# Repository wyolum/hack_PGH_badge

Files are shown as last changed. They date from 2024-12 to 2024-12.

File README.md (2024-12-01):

# hack_PGH_badge
* Badge PCB kit for hackPGH, for "learn to solder" and "learn to lasercut" classes
* Can be used for basic soldering (through hole parts) or advanced soldering (surface mount parts)

***FEATURES***
1. Four LED's with series current limit resistors
2. Two CR2032 Coin Batteries
3. Use slow fade multi-color LEDs, or all White LEDs or whatever you choose
5. The simple version is just battery, resistors and LEDs.
6. The fancy version is with two US1881 magnetic hall latch sensors - see notes in the schematic (PDF)

***RENDERS***
rev1 renders
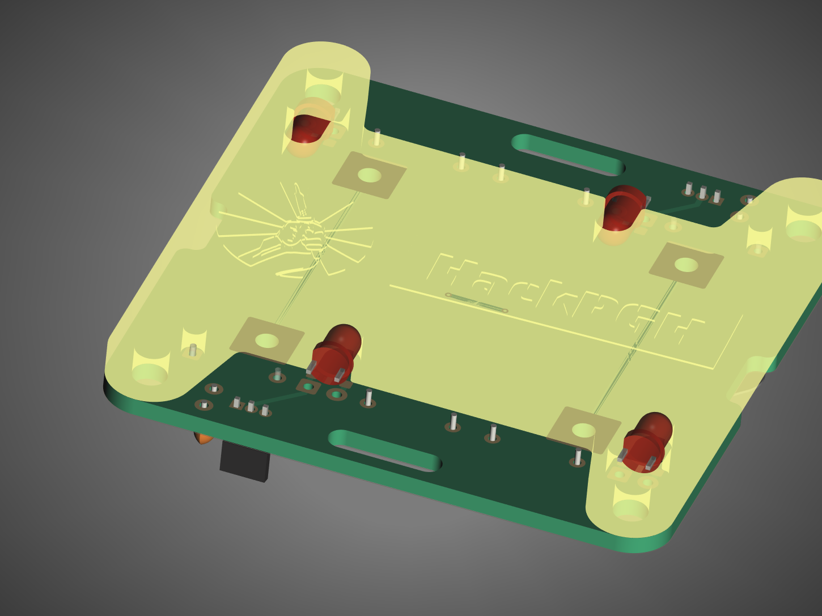
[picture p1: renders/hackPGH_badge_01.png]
hackPGH Badge


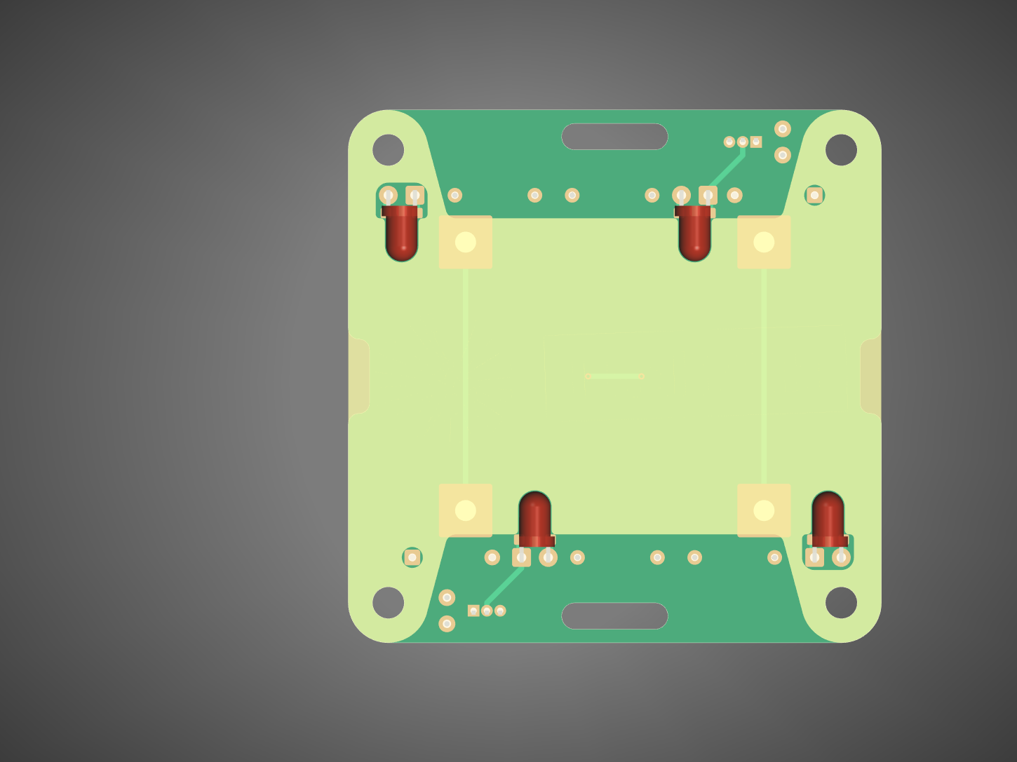
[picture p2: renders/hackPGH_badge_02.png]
hackPGH Badge


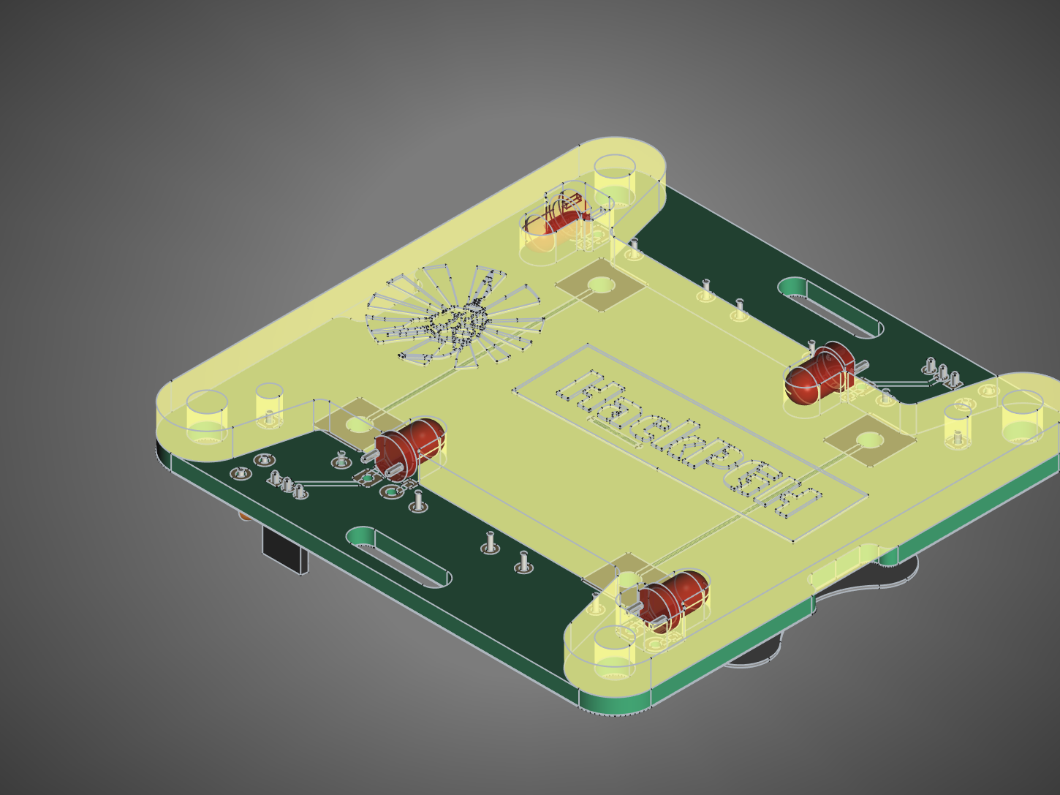
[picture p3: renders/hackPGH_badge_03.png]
hackPGH Badge


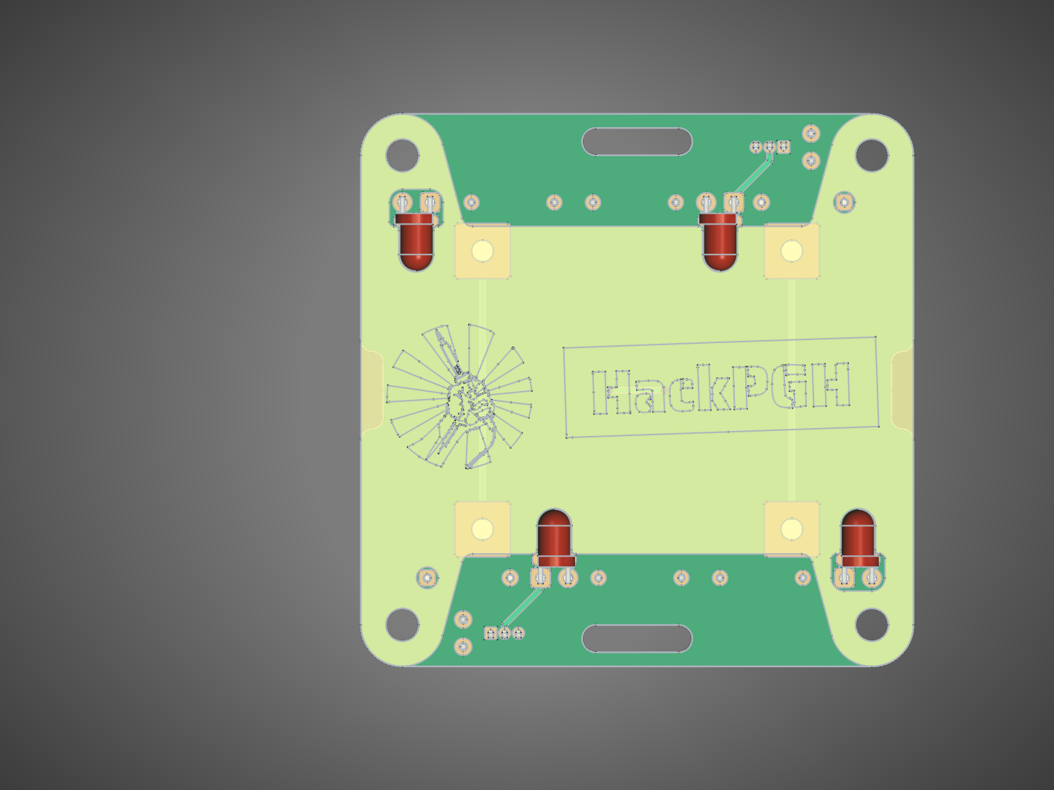
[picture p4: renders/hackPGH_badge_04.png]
hackPGH Badge


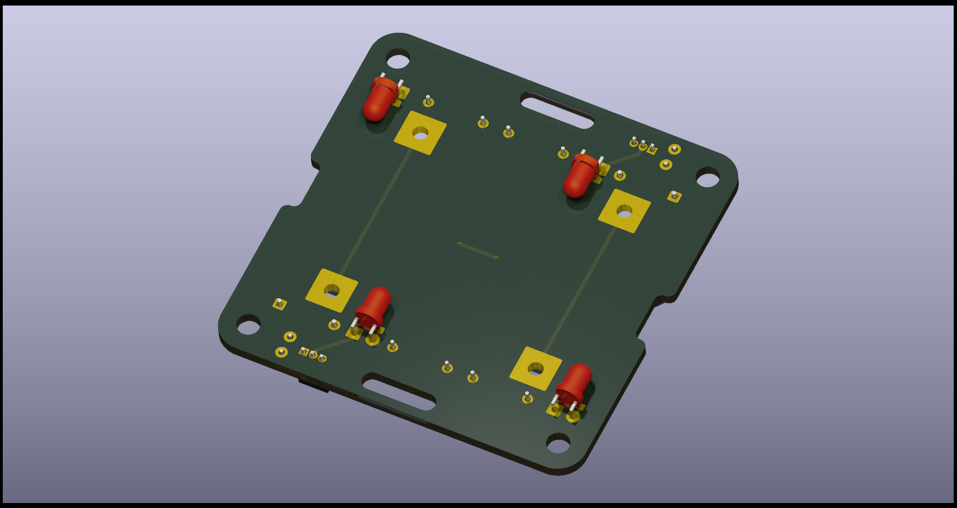
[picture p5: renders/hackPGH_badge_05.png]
hackPGH Badge


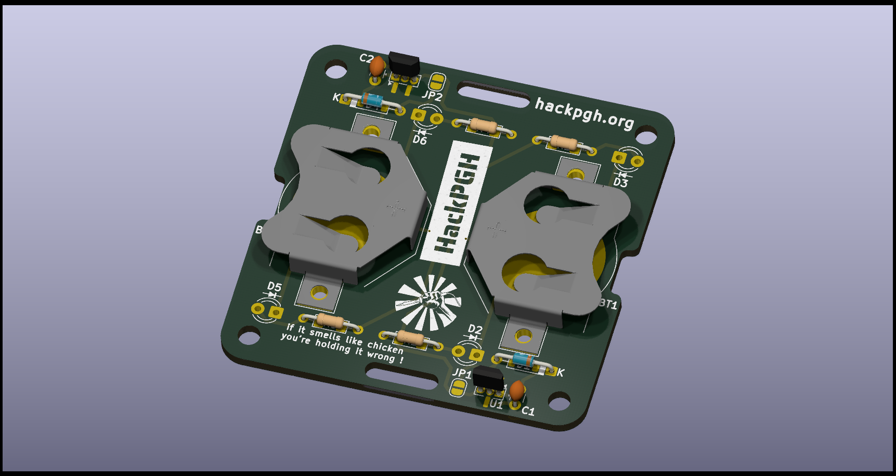
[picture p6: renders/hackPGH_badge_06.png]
hackPGH Badge


License
-------
[CERN Open Hardware Licence v1.2 ]

[CERN Open Hardware Licence v1.2 ]:http://www.ohwr.org/attachments/2388/cern_ohl_v_1_2.txt

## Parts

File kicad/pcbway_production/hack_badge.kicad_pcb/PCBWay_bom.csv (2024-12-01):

Designator | Quantity | Value | Footprint | Package | MPN | DNP | Mount_Type | Description | MF | MAXIMUM_PACKAGE_HEIGHT | Check_prices | STANDARD | PARTREV | SnapEDA_Link | MP | Description_1
BT1, BT2 | 2 | 3V | BatteryHolder_Keystone_3002_1x2032 |  |  |  | smt | CR2032
C1, C2 | 2 | 100nF | C_Disc_D3.0mm_W1.6mm_P2.50mm |  |  |  | tht | Unpolarized capacitor
D1, D4 | 2 | D_Schottky | D_SOD-123_DO-34_SOD68_P7.62mm_Horizontal |  |  |  | tht | Schottky diode, filled shape
D2, D3, D5, D6 | 4 | LED | LED_D3.0mm_Dialight_598 |  |  |  | tht | Light emitting diode, filled shape
R1, R2, R3, R4 | 4 | 2E2 | R_1206_Axial_DIN0204_L3.6mm_D1.6mm_P7.62mm_Horizontal |  |  |  | tht | Resistor
U1, U2 | 2 | US1881EUA-AAA-000-BU | TO92127P410H430-3_TSOT-23 | TO-92-3L-3 Melexis |  |  | tht |  | Melexis Technologies | 4.3mm | https://www.snapeda.com/parts/US1881EUA-AAA-000-BU/Melexis+Technologies+NV/view-part/?ref=eda | IPC-2221/IPC-2222 | 010 | https://www.snapeda.com/parts/US1881EUA-AAA-000-BU/Melexis+Technologies+NV/view-part/?ref=snap | US1881EUA-AAA-000-BU | Digital Switch Latch Open Drain Hall Effect TO-92-3

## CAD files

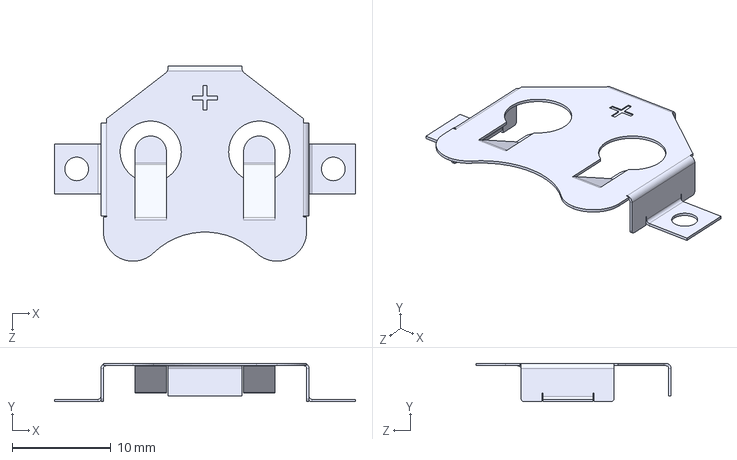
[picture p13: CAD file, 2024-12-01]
3D_2D_assets/BAT_HLD_003_SMT/BAT-HLD-003-SMT.step
30.5 x 3.90 x 19.8 mm

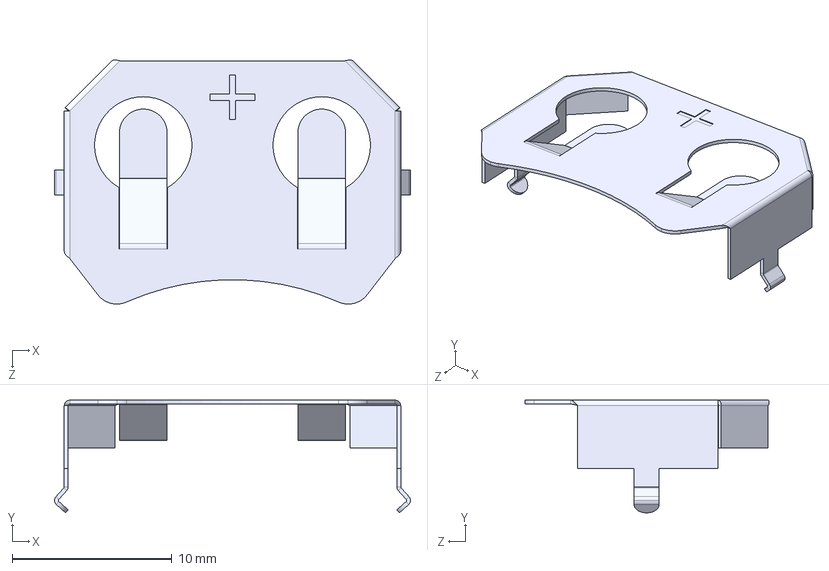
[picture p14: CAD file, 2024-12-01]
3D_2D_assets/BK_913/BK-913.step
22.3 x 7.06 x 15.3 mm

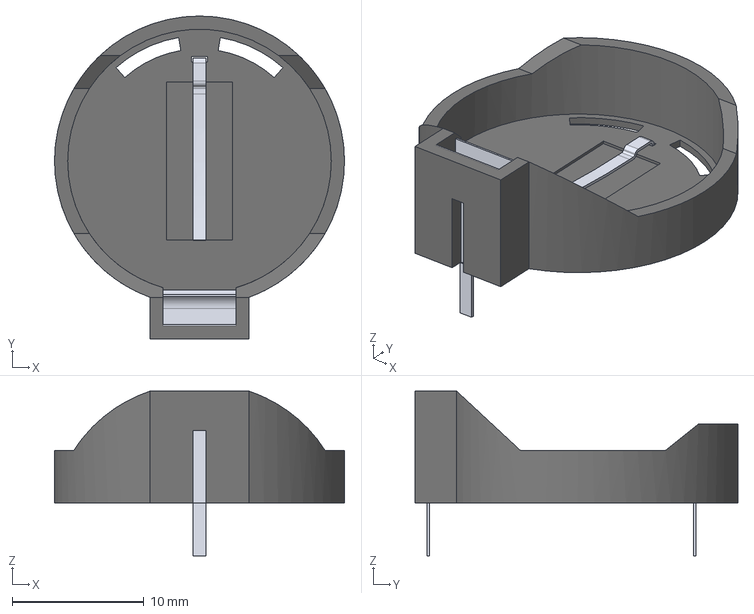
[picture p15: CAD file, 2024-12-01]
3D_2D_assets/CR2032_HOR_HOLD.step
22.0 x 24.5 x 12.5 mm

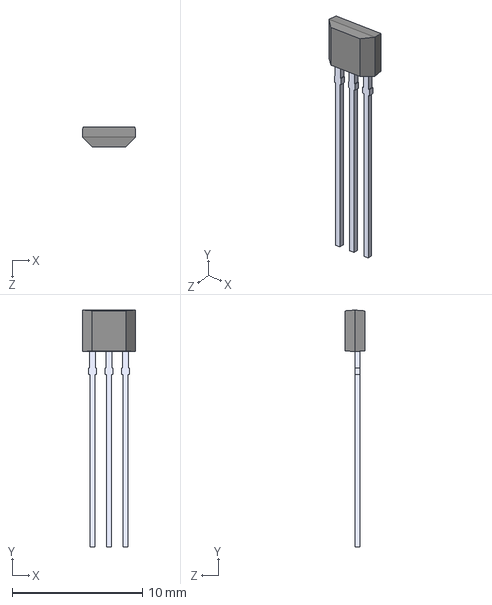
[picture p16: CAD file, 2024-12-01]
3D_2D_assets/US1881EUA-AAA-000-BU/US1881EUA-AAA-000-BU.step
4.10 x 18.2 x 1.50 mm

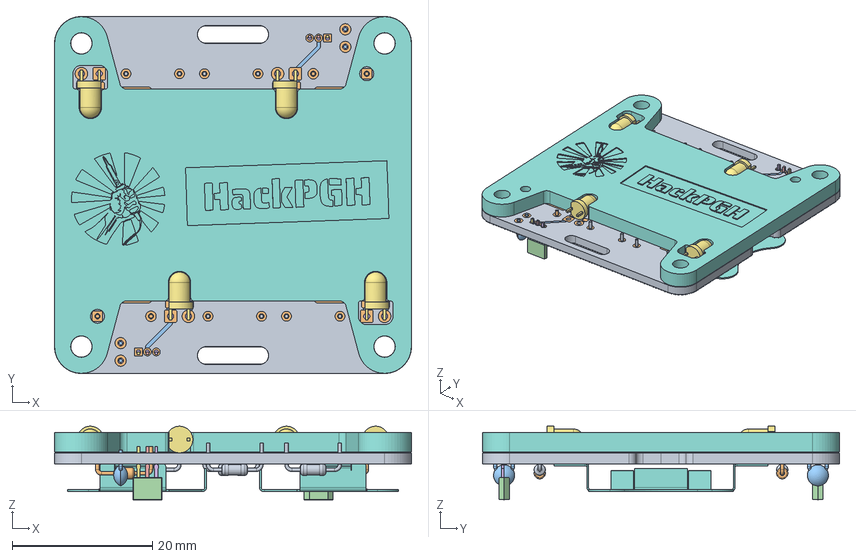
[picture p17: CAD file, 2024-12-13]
freecad/hackPGH_badge_v2.FCStd
50.9 x 50.9 x 10.5 mm
Pcb_8119
topPads_8119
topTracks_8119
botPads_8119
botTracks_8119
botSilks_2b00
D5_LED_D3.0mm_4dba36d6a966 x 4
BT1_BAT-HLD-003-SMT_d9d281af9b58 x 2
R1_R_Axial_DIN0204_L36mm_D16mm_P762mm_Horizontal_dcc7a843ff6f x 4
D4_D_DO-34_SOD68_P7.62mm_Horizontal_3fdec8da069c x 2
C2_C_Disc_D30mm_W20mm_P250mm_ea60b1ea7e60 x 2
TO92127P410H430-3 x 2
TO92127P410H430-004 x 2
TO92127P410H430-005 x 2
TO92127P410H430-006 x 2
Body_Acrylic

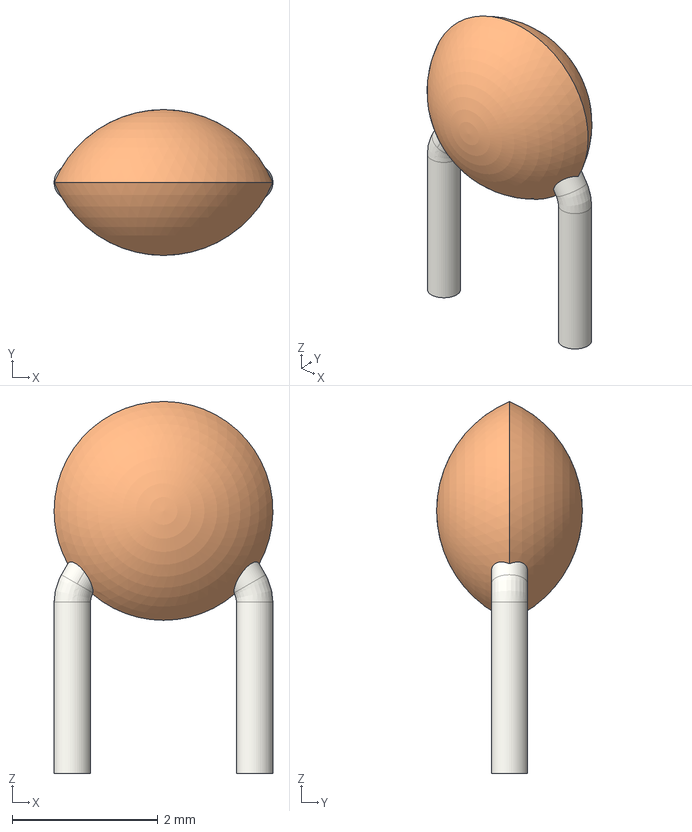
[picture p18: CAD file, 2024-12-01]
kicad/Library_3D_CAD_models/C_Disc_D3.0mm_W2.0mm_P2.50mm.step
3.00 x 2.00 x 5.10 mm

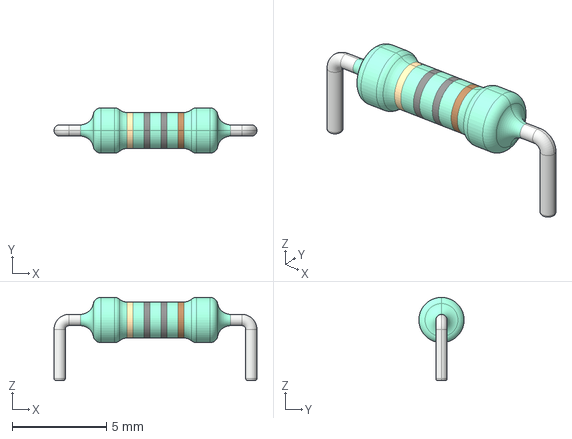
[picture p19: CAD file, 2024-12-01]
3D_2D_assets/Res40-Axial_Short_0.25W-10R.step
10.8 x 2.40 x 4.41 mm

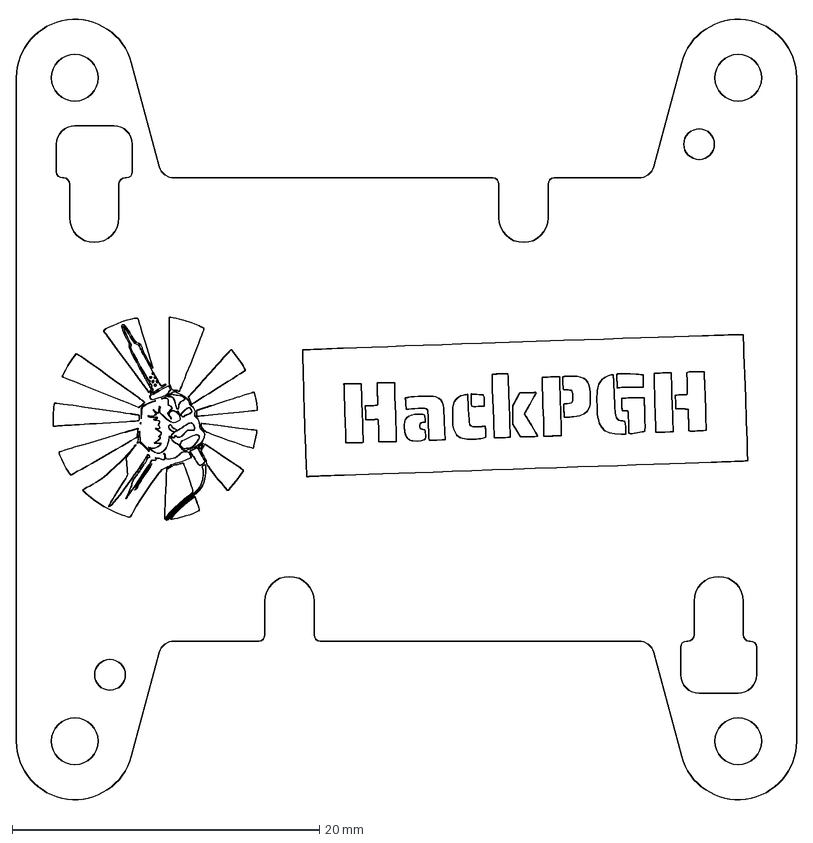
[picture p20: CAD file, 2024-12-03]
freecad/hackPGH_badge_v2_acrylic.dxf
50.8 x 51.2 mm

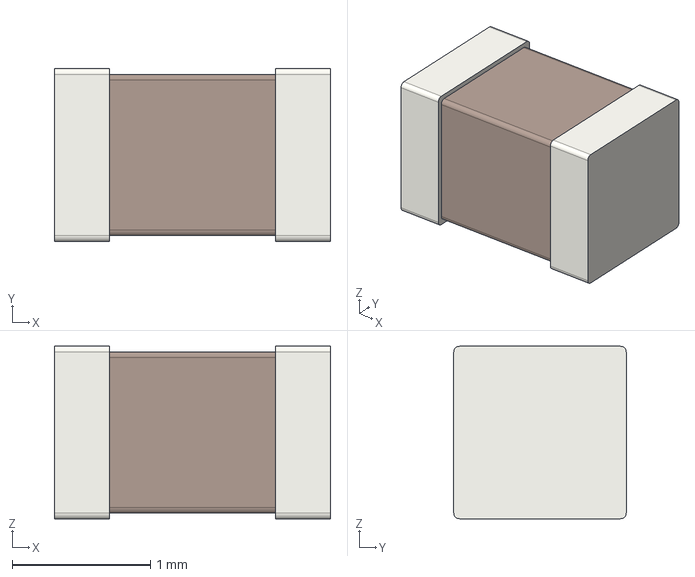
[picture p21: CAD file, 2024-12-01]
kicad/Library_3D_CAD_models/C_0805_2012Metric.step
2.00 x 1.25 x 1.25 mm

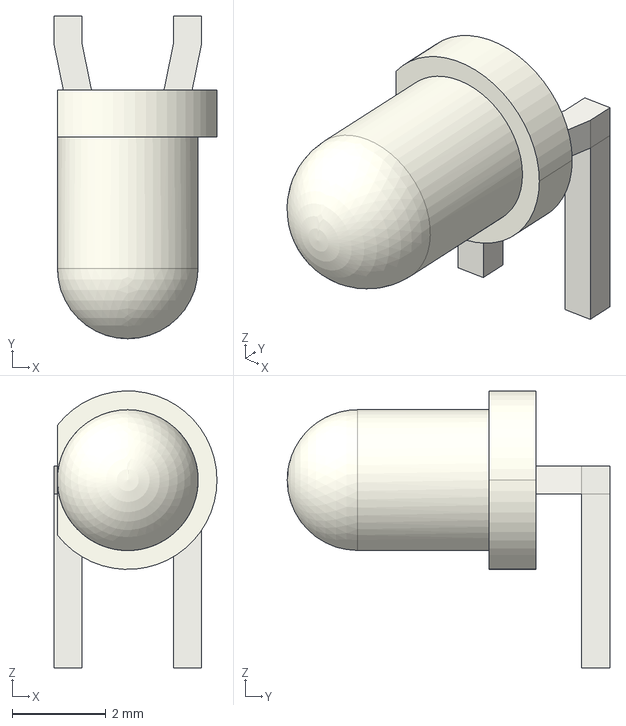
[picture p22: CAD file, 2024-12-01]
3D_2D_assets/LED_D3.0mm_Horizontal_O1.27mm_Z2.0mm_Clear.step
3.47 x 6.87 x 5.90 mm

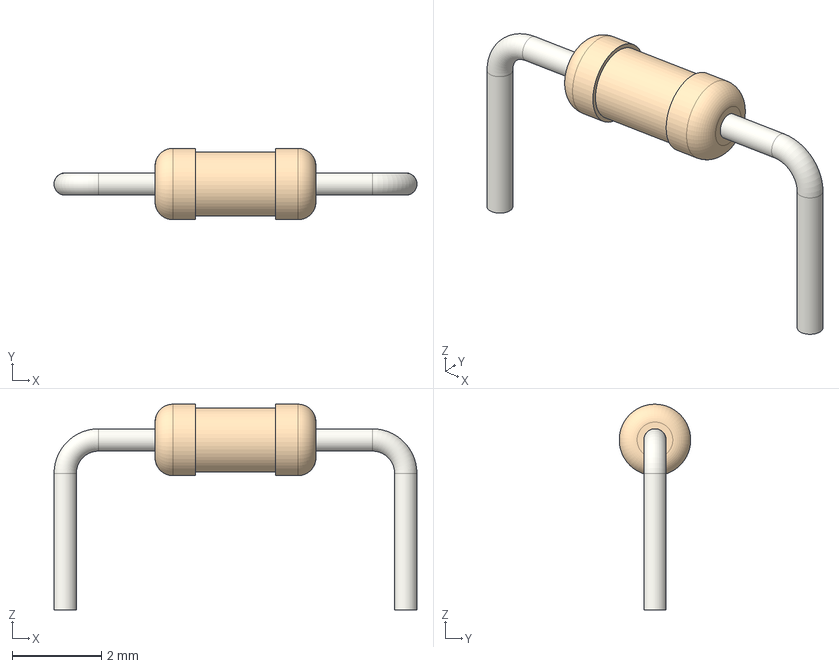
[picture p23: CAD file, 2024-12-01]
kicad/Library_3D_CAD_models/R_Axial_DIN0204_L36mm_D16mm_P762mm_Horizontal.step
8.12 x 1.60 x 4.60 mm

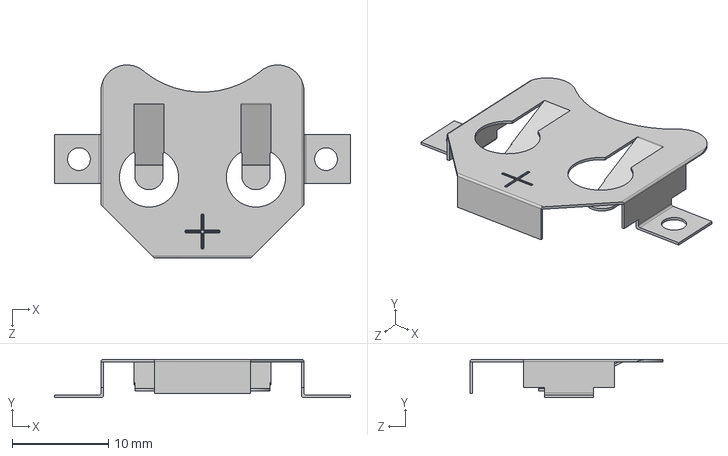
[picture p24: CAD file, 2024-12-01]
3D_2D_assets/User Library-3002.step
30.7 x 3.96 x 20.1 mm

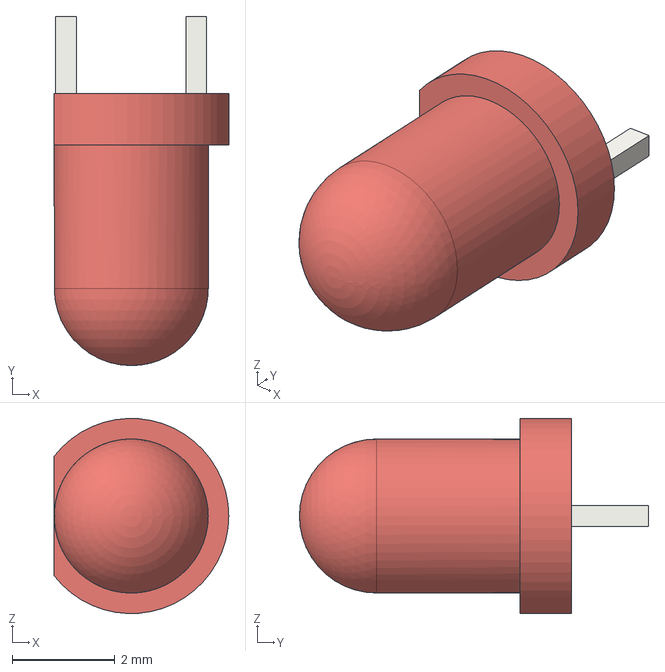
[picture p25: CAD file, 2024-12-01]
kicad/Library_3D_CAD_models/LED_D3.0mm.step
3.40 x 6.80 x 3.80 mm

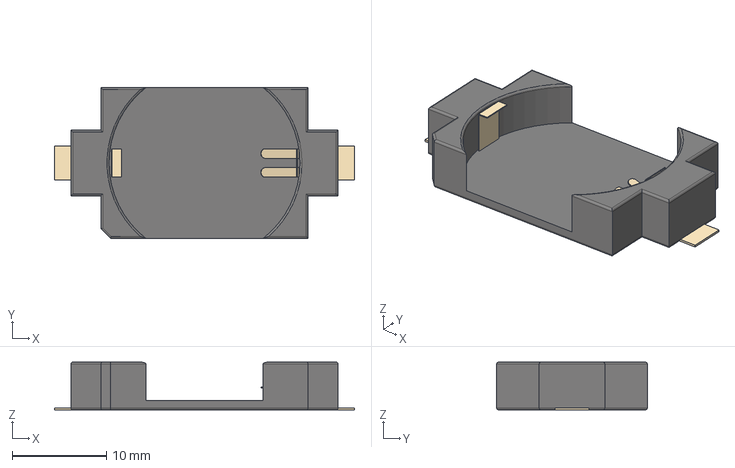
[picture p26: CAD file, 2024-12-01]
3D_2D_assets/BatteryHolder_Keystone_1060_1x2032.step
31.9 x 16.0 x 5.08 mm

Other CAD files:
kicad/Library_3D_CAD_models/BAT-HLD-003-SMT.step
kicad/Library_3D_CAD_models/D_DO-34_SOD68_P7.62mm_Horizontal.step
3D_2D_assets/hackPGH_logo_01.dxf
3D_2D_assets/5871034147F.stp
freecad/archive/hackPGH_badge_v1.FCStd
freecad/hackPGH_badge_v1.FCStd
freecad/hack_badge-B_Silkscreen.dxf
kicad/Library_3D_CAD_models/TO92127P410H430-3.step

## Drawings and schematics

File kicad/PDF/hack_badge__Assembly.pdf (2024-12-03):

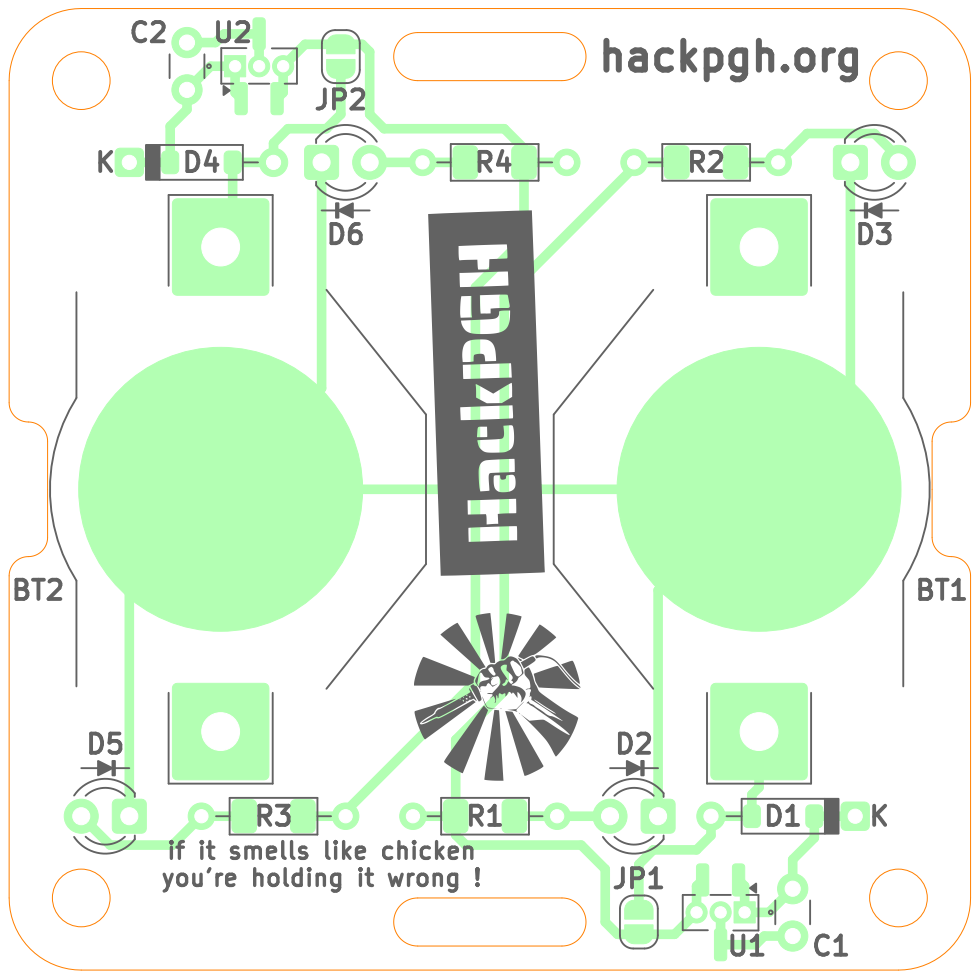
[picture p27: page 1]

if it smells like chicken

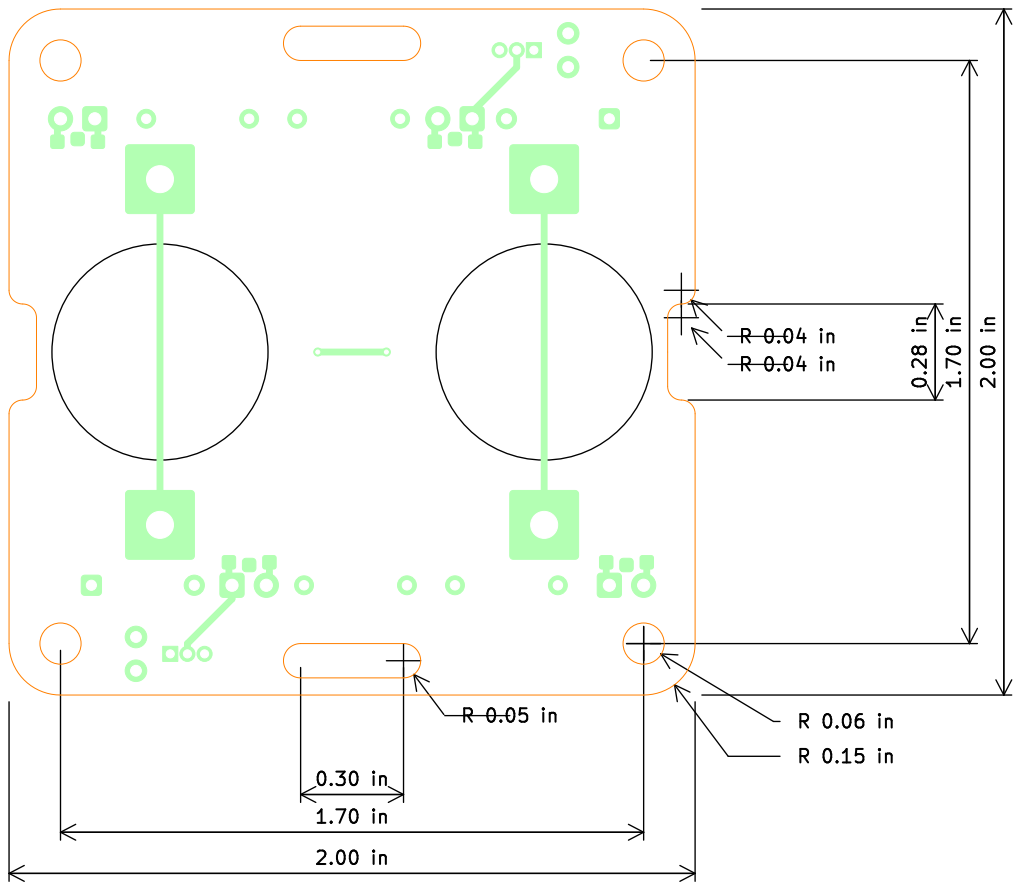
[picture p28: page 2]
D Date: 2024-11-24 KiCad; E.D.A. 8.0.6 Size: A4; Rev: v1; Id: 1/1 Title: hack_Badge; File: hack_badge.kicad_pcb Sheet: Colored; TOP; hackPGH; Badge - learn to solder + learn to lasercut Anool Mahidharia; Wyolum; Board2Pdf:; Colored; TOP -; Page 2/2

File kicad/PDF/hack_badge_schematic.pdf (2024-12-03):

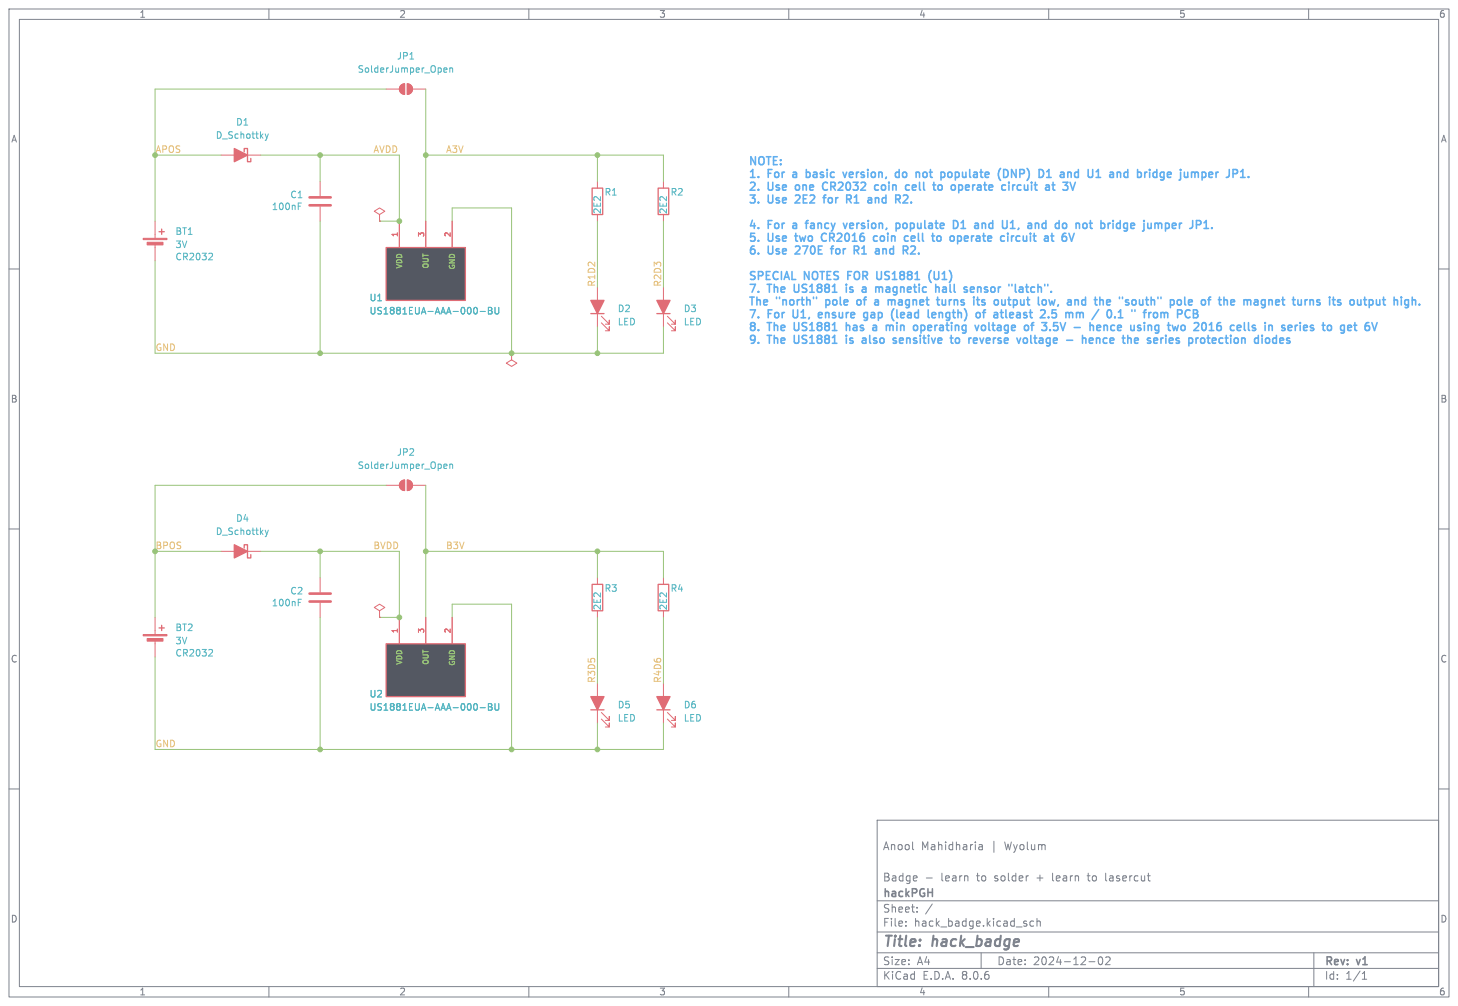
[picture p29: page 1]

6. Use 270E for R1 and R2. SPECIAL NOTES FOR US1881 (U1) 7. The US1881 is a magnetic hall sensor "latch". The "north" pole of a magnet turns its output low, and the "south" pole of the magnet turns its output high. 7. For U1, ensure gap (lead length) of atleast 2.5 mm / 0.1 " from PCB

LED VDD
9. The US1881 is also sensitive to reverse voltage - hence the series protection diodes U2 US1881EUA-AAA-000-BU VDD

8. The US1881 has a min operating voltage of 3.5V - hence using two 2016 cells in series to get 6V

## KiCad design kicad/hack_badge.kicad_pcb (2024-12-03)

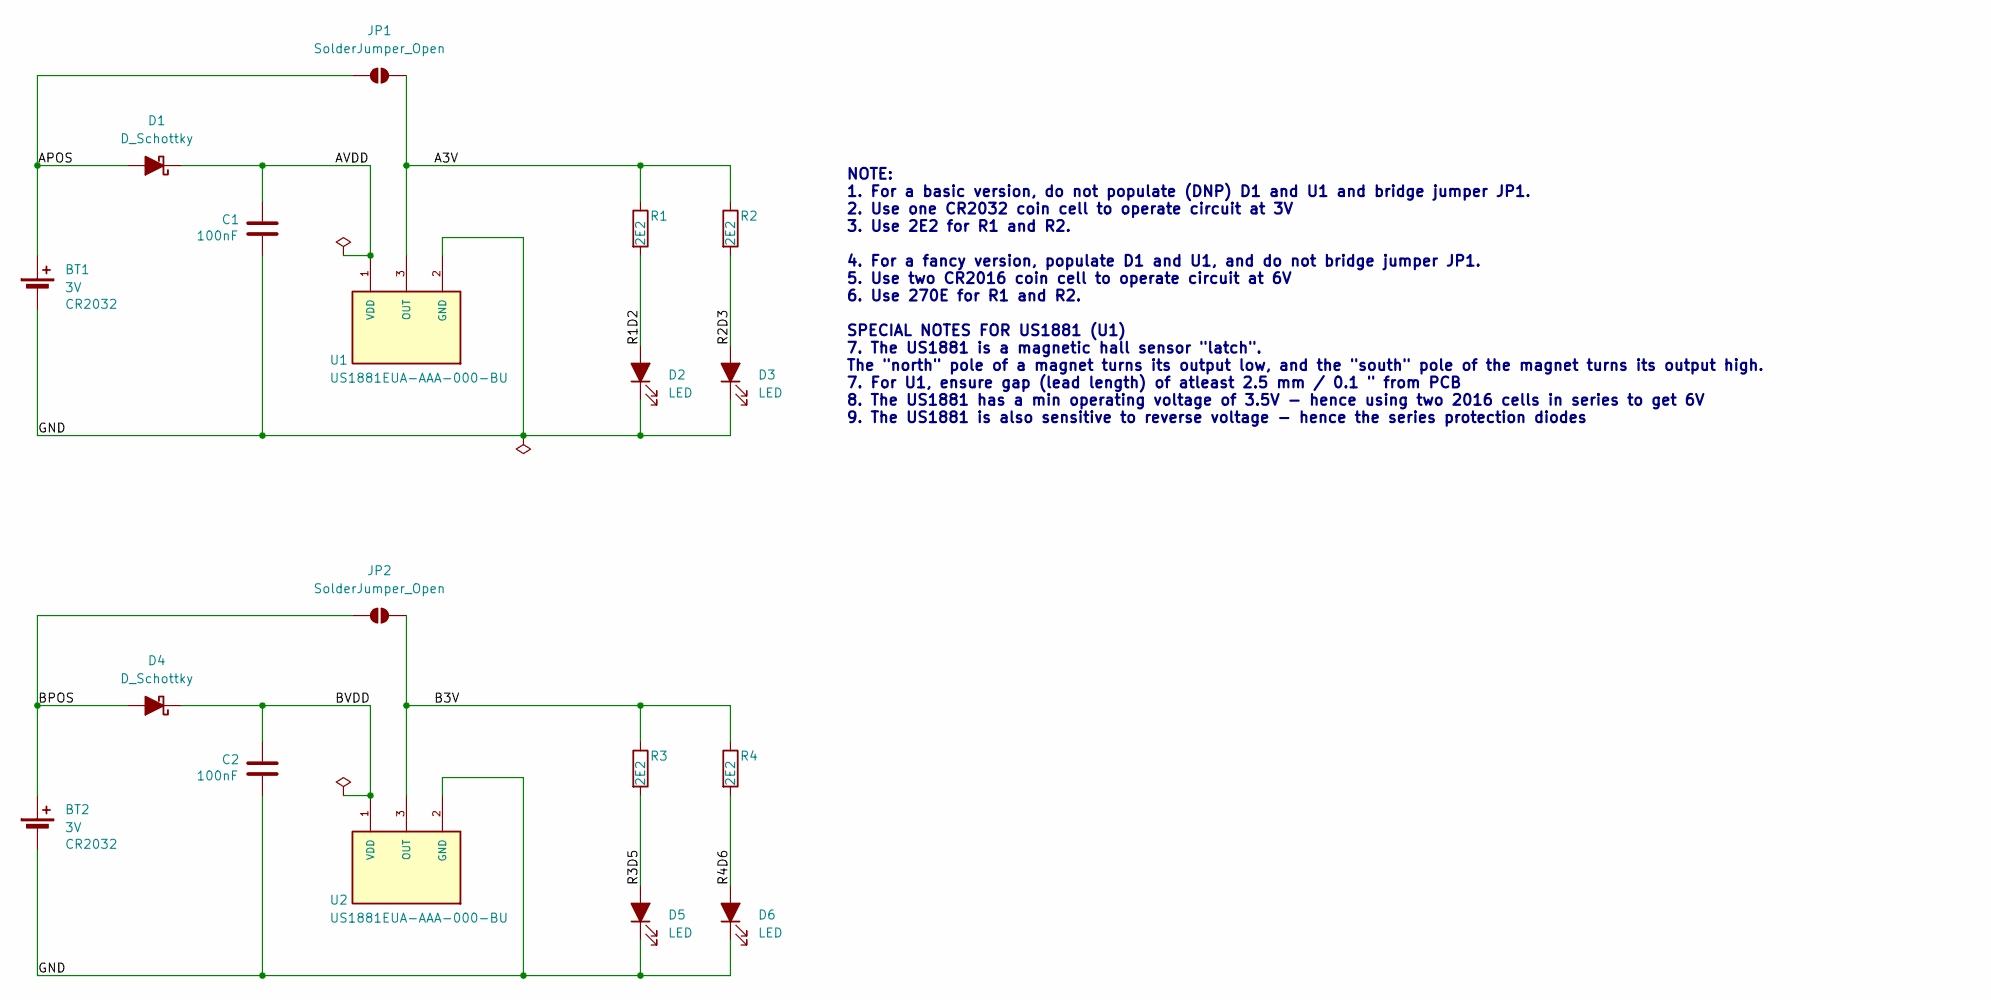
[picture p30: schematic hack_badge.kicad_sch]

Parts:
BT1, BT2: 3V; BatteryHolder_Keystone_3002_1x2032
C1, C2: 100nF; C_Disc_D3.0mm_W1.6mm_P2.50mm
D1, D4: D_Schottky; D_SOD-123_DO-34_SOD68_P7.62mm_Horizontal
D2, D3, D5, D6: LED; LED_D3.0mm_Dialight_598
JP1, JP2: SolderJumper_Open; SolderJumper-2_P1.3mm_Open_RoundedPad1.0x1.5mm
R1, R2, R3, R4: 2E2; R_1206_Axial_DIN0204_L3.6mm_D1.6mm_P7.62mm_Horizontal
U1, U2: US1881EUA-AAA-000-BU; TO92127P410H430-3_TSOT-23; PARTREV 010

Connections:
/A3V: JP1.2 (B), R1.1, R2.1, U1.3 (OUT)
/APOS: BT1.1 (+), D1.2 (A), JP1.1 (A)
/AVDD: C1.1, D1.1 (K), U1.1 (VDD)
/B3V: JP2.2 (B), R3.1, R4.1, U2.3 (OUT)
/BPOS: BT2.1 (+), D4.2 (A), JP2.1 (A)
/BVDD: C2.1, D4.1 (K), U2.1 (VDD)
/GND: BT1.2 (-), BT2.2 (-), C1.2, C2.2, D2.1 (K), D3.1 (K), D5.1 (K), D6.1 (K), U1.2 (GND), U2.2 (GND)
/R1D2: D2.2 (A), R1.2
/R2D3: D3.2 (A), R2.2
/R3D5: D5.2 (A), R3.2
/R4D6: D6.2 (A), R4.2

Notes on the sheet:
NOTE: 1. For a basic version, do not populate (DNP) D1 and U1 and bridge jumper JP1. 2. Use one CR2032 coin cell to operate circuit at 3V 3. Use 2E2 for R1 and R2. 4. For a fancy version, populate D1 and U1, and do not bridge jumper JP1. 5. Use two CR2016 coin cell to operate circuit at 6V 6. Use 2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

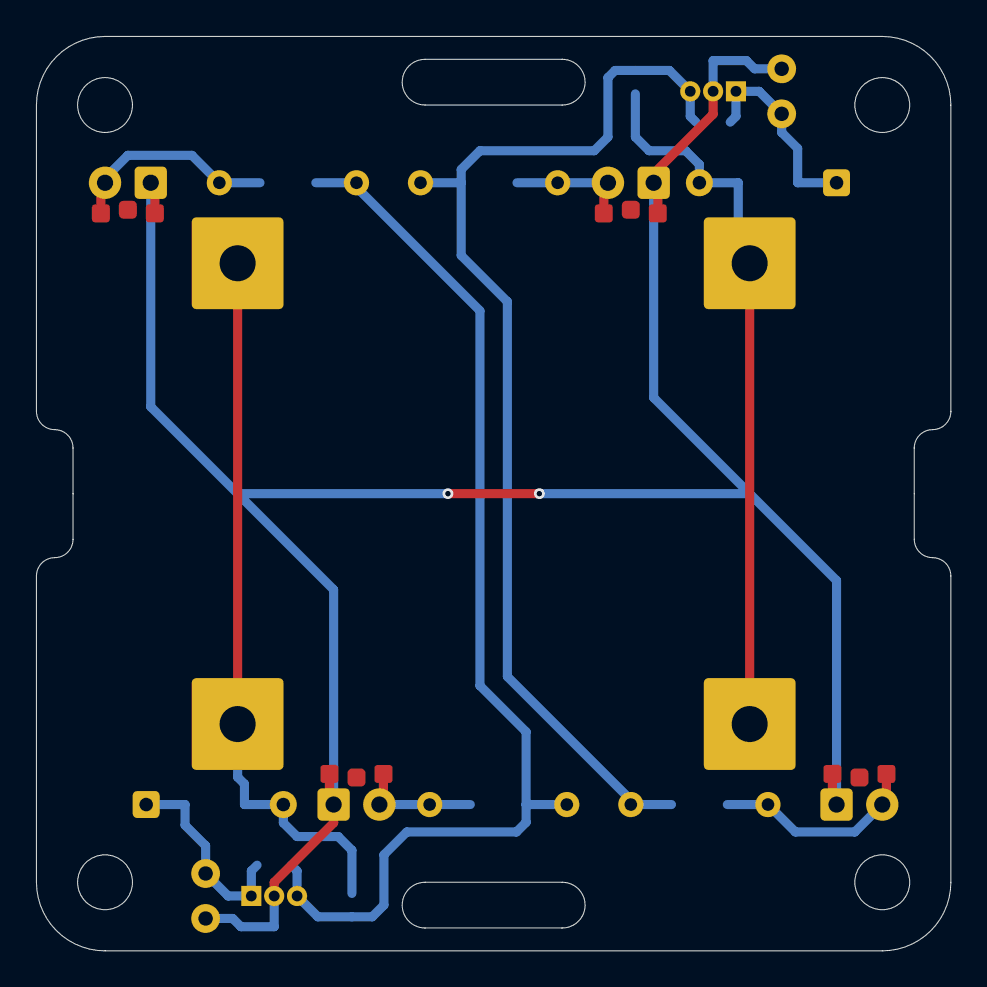
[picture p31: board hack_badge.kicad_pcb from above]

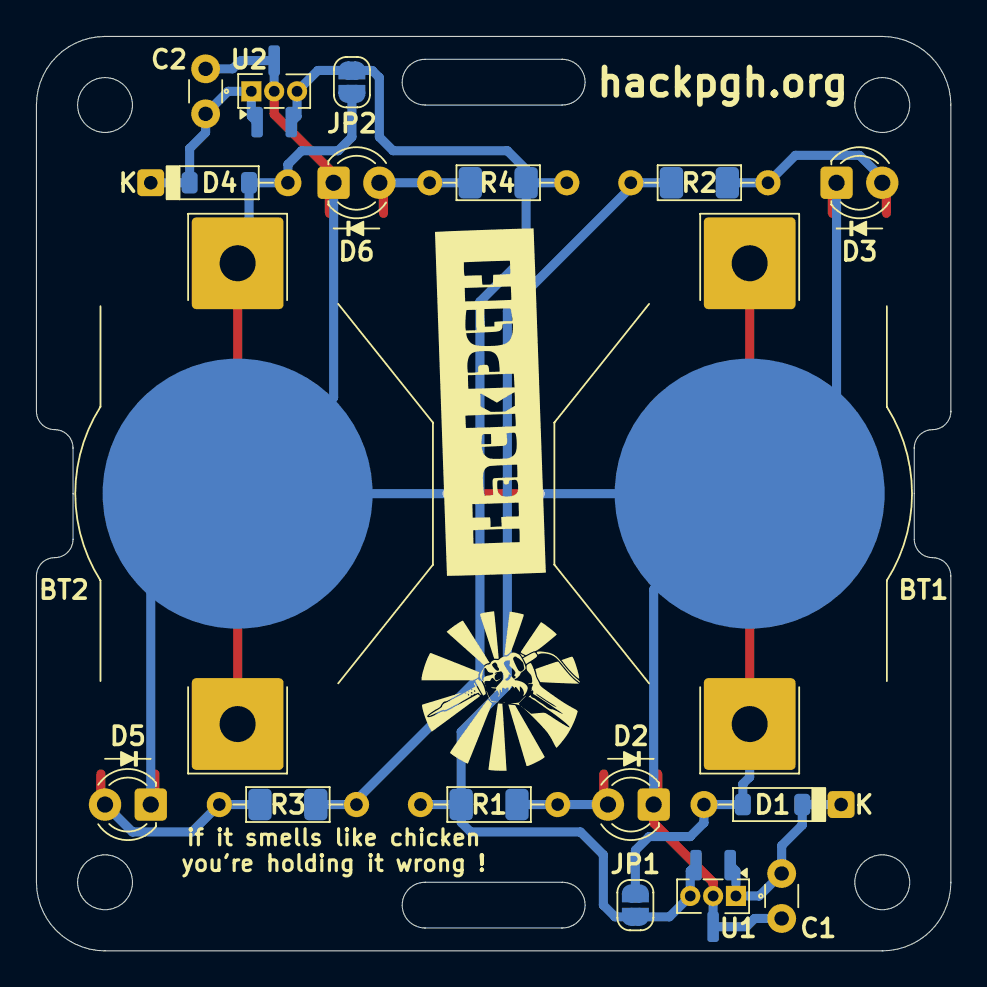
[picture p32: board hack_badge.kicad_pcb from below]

Board: 2 copper layers, 50.8 x 50.8 mm, 18 parts (14 on the bottom side), 11 nets.

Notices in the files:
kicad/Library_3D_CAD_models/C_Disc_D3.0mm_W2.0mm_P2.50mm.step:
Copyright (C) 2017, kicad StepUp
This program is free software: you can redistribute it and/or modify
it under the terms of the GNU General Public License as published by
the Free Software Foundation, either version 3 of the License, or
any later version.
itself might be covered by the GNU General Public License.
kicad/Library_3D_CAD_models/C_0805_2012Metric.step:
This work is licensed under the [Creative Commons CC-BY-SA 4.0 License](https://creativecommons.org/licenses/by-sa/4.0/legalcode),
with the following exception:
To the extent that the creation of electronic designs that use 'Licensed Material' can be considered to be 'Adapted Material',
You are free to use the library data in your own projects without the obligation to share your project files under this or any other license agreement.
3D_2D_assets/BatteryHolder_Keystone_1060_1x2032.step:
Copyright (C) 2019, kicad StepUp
